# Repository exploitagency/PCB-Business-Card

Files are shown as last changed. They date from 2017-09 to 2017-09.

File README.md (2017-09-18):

PCB Business Card by: Corey Harding  
http://www.LegacySecurityGroup.com  
  
My PCB "business card" was designed with a credit card sized form factor in mind to easily fit into a wallet. The board also doubles as an ATtiny85 development board with pins broke out and a prototyping area. The ATtiny85 is pre-programmed to type out my contact info when a capacitive touch sensor is activated. There are also several optional through hole component upgrades for the end user to experiment with. You can even program the board using the Arduino IDE. It is preloaded with a custom 1s delay micronucleus bootloader and it is digispark compatible.  
  
I have seen other similar PCB business cards out there but I made sure to make my project easy for people to modify for personal use as well as allowing the person receiving the business card to have something extra to play with. I believe the ease of use and giving the end user something functional vs just something to look at and throw away is what makes my project stand out. Not to mention capacitive touch sensors are always fun to use!  
  
Video Demo  
-----  
Click image below to view  
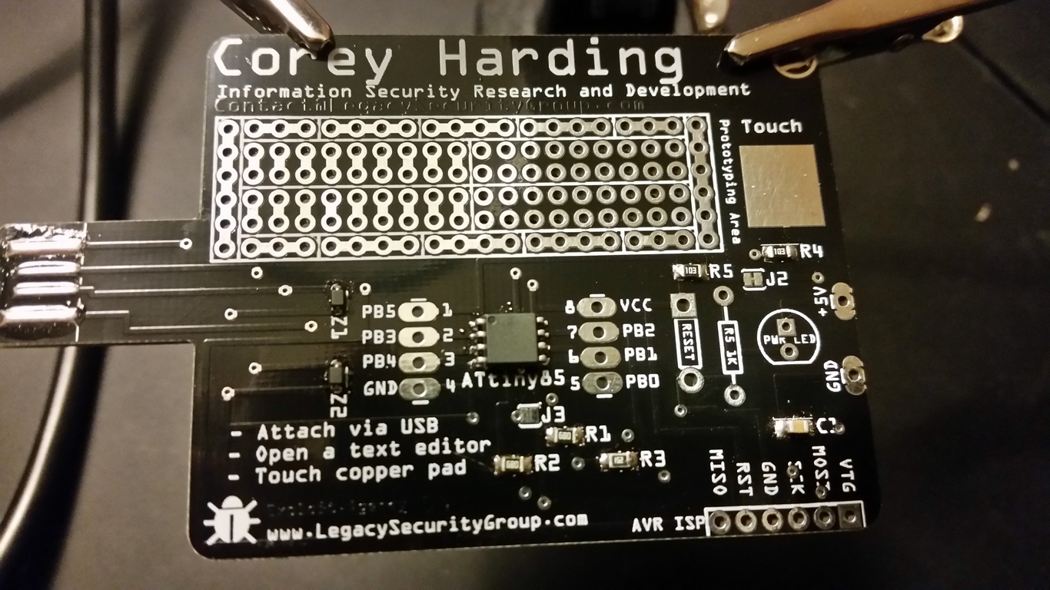
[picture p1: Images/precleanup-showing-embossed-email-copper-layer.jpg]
Video Demo (https://youtu.be/Ss94M5kzOXM)
  
Image is of the board before the cleanup process but it shows off the embossed copper email address well.  
  
Hardware License  
-----  
Attribution-ShareAlike 3.0 Unported (CC BY-SA 3.0)  
https://creativecommons.org/licenses/by-sa/3.0/  
The hardware is based on the minimal schematic for a digispark/micronucleus compatible board. A few parts have also been added for better stability as well as a capacitive touch sensor. Gerber files are included in the repo to send immediately to a board house as well as Fritzing PCB files to allow users to easily customize my board design and export your own Gerber files.  
  
Software  
-----  
Utilizes the TinyTouchLib: https://github.com/cpldcpu/TinyTouchLib  
Bootloader: https://github.com/micronucleus/  
  
Initial programming instructions if building the board from scratch.  
-----  
(Any of my assembled boards already have the bootloader burned in)  
Fuse: avrdude -c buspirate -P /dev/ttyUSB1 -p attiny85 -U lfuse:w:0xe1:m -U hfuse:w:0xdd:m -U efuse:w:0xfe:m -B 20  
Burn Bootloader: avrdude -c buspirate -P /dev/ttyUSB1 -p attiny85 -U flash:w:bootloader.hex:i -B 20  
The Micronucleus build included has a custom 1 second programming delay before running the application.  
The default 6 second delay was too long to wait to run the application for my specific use case.  
  
Programming the application portion via the Arduino IDE.  
-----  
File - Preferences - Additional Board Manager URLs - http://digistump.com/package_digistump_index.json - OK  
Tools - Board - Boards Manager... - Digistump AVR Boards - Install  
Board: Digispark (Default - 16.5mhz)  
Programmer: Micronucleus  
  
Jumpers  
-----  
Cut J1 to disable the capacitive touch sensor.  
Cut J2 to disable R5 resistor from RST to VCC.  
Bridge J3 to enter programming mode when flashed with a different Micronucleus build.  
  
Optional Features  
-----  
Reset Switch  
Power LED - Requires 1K Resistor  
Utilizing the Prototyping Area  
Flashing a new application via USB  
Flashing via the AVR ISP header(Do not connect a programmer while connected to a USB port)  
  
Notes  
-----  
The board thickness is 1.6mm and requires a shim to fit snugly into the USB port.  
Currently a blank PVC ID card is cut to size and bonded using Loctite 495 Instant Adhesive.  
This has proven so far to be a fast, strong, and relatively consistent solution.  
  
Enjoy!

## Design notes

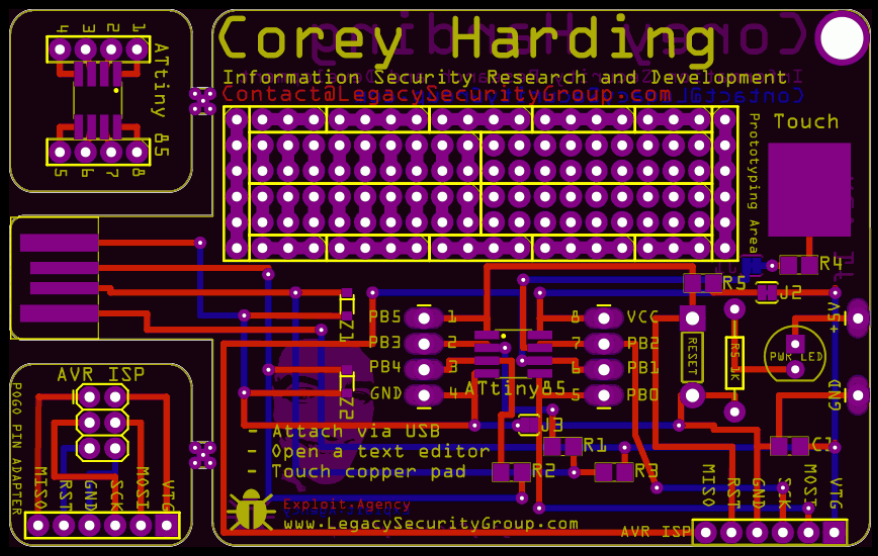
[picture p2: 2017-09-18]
Images/panelized-easyeda-gerber-viewer.png

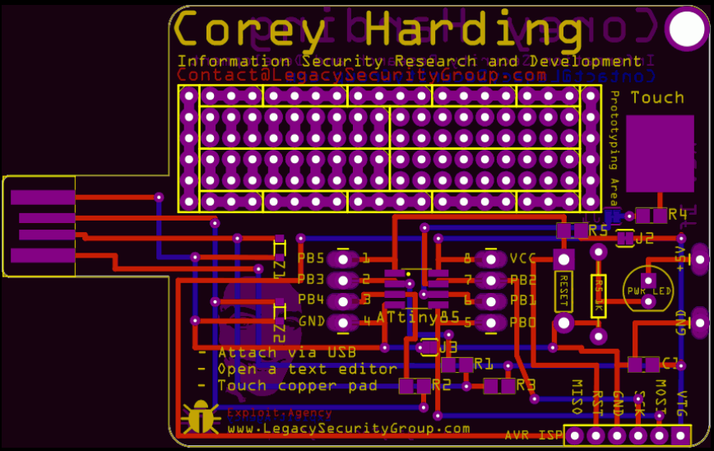
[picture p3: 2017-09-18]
Images/easyada-gerber-viewer.png

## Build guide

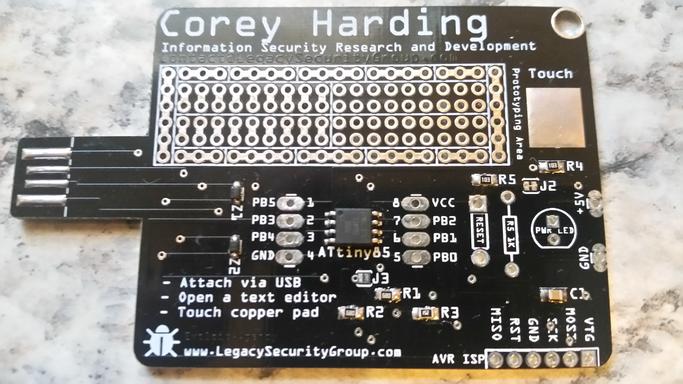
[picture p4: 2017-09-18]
Images/assembled-board.jpg

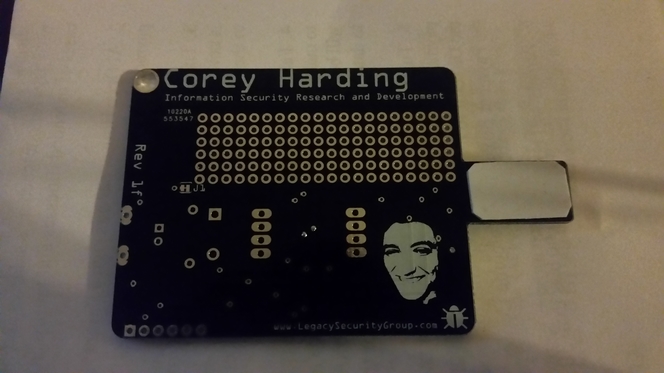
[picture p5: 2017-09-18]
Images/assembled-board-back.jpg

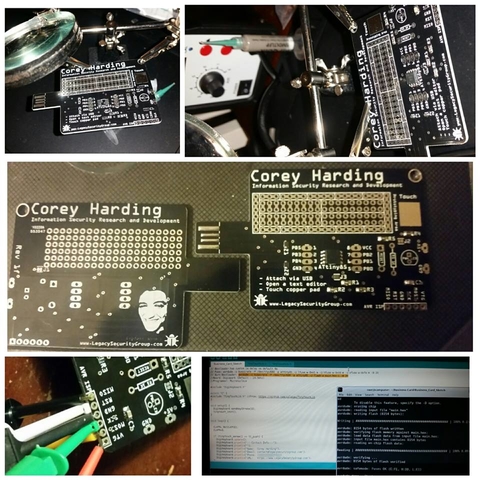
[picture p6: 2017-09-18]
Images/assembly-and-programming.jpg

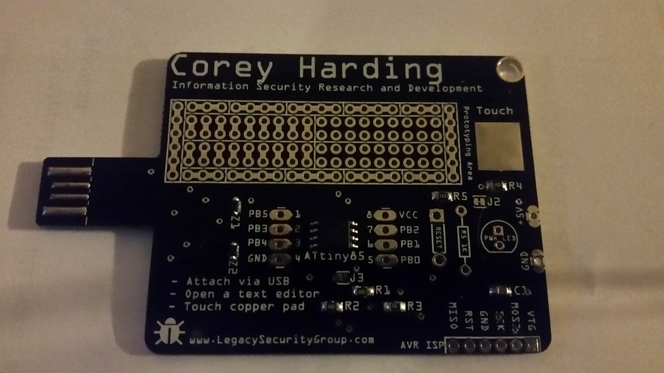
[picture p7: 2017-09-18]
Images/assembled-board-front.jpg

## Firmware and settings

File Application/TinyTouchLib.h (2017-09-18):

//From: https://github.com/cpldcpu/TinyTouchLib
/*
 * TinyTouchLib.h
 *
 * Created: 09.06.2013 17:25:47      - v0.1 Initial release (Attiny 10)
 *      10.06.2013          -   v0.2 ported to ATtiny 25/45/85 and ATtiny13     
 *  Author: Tim (cpldcpu@gmail.com) 
 */ 

#ifndef TINYTOUCHLIB_H_
#define TINYTOUCHLIB_H_
#include <avr/io.h>

enum {tt_off=0,tt_on,tt_push,tt_release,tt_timeout};

//////////////////////////////////////////////////////////////////////////
//
// User definable settings
//
//////////////////////////////////////////////////////////////////////////

// Define upper and lower threshold for the touch sensing. You may have to
// change these depending on the geometry of your touch button.
// Setting the "on" value lower will make the touch button more sensitive.
// Setting the "off" value higher will make the touch button less likely
// to be "stuck". Too high values can lead to oscillations.

#define touch_threshold_on 60
#define touch_threshold_off 20

// If the touch button is pressed, the bias value is not updated
// to prevent detection of multiple touches. In some cases this may
// lead to a "stuck button" situation. Therefore an update of the bias
// is forced after a certain time unless this function is deactivated.
//
// The value of timeout corresponds to the number of calls to tinytouch_sense().
// The maximum is 255. 
// Setting timeout to 0 will turn the functionality off.

#define touch_timeout 255
//#define touch_timeout 0   // turn off timeout functionality


// Define pins to use for the reference input and the touch button
// The reference pin is used to charge or discharge the internal
// sample&hold capacitor. This pin is used in output mode and should
// not be shorted to VCC or GND externally.
// The sense pin is connected to the touch-button. To improve noise immunity
// a series resistor can be used.

// The pin number must match the corresponding analog input number ADCx. 
// Default port is PORTB. (ATtiny 5/10/13/25/45/85)

#define tt_refpin 0   // Use PB0 as reference pin
#define tt_refadc 0   // Use ADC0 as reference ADC input
#define tt_sensepin 2 // Use PB3 as sense pin
#define tt_senseadc 1 // Use ADC1 as sense ADC input
      
//////////////////////////////////////////////////////////////////////////
//
// Library functions
//
//////////////////////////////////////////////////////////////////////////

// Library initialization
// Call this once to initialize the library functions and the ADC converter
void  tinytouch_init(void);

// The sense function evaluates the button state and performs internal 
// housekeeping. It should be polled at least 30 times per second to
// update the internal logic. Please note that each call performs 32
// analog to digital conversions with active waiting. This may take 
// several ms.

// Possible return values are:
//    tt_off=0  No touch sensed
//    tt_on   Touch button is active and touch is sensed.
//    tt_push   Touch button is pushed. Use this to initiate one time events.
//    tt_release  Touch button is released. Use this to initiate one time events.
//    tt_timeout  Touch button has been active too long and internal bias was reset. 
uint8_t tinytouch_sense(void);

#endif
